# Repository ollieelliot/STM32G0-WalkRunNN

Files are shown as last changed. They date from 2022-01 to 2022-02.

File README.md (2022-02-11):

# Motion detection on an STM32G0 microcontroller

# Hardware: 
  - The Schematic and PCB is designed in KiCad and uses the STM32G041J6M6 ARM Cortex-M0 Microcontroller together with an MPU6050 (Gyroscope and Accelerometer).

# Software (currently working on):
- Uses a neural network trained in Python and [emlearn](https://github.com/emlearn/emlearn) to save the weights, biases and activation functions to a header file in order to run inference in C.

# Pictures:
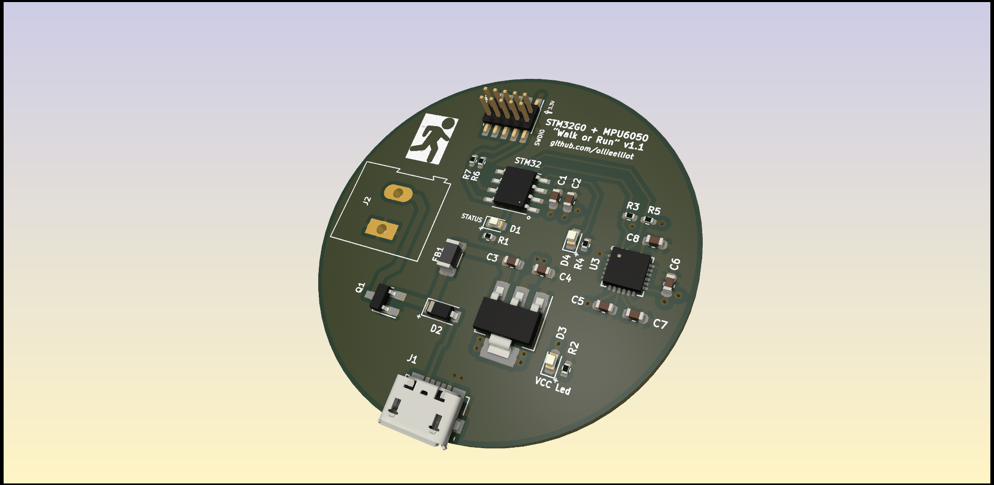
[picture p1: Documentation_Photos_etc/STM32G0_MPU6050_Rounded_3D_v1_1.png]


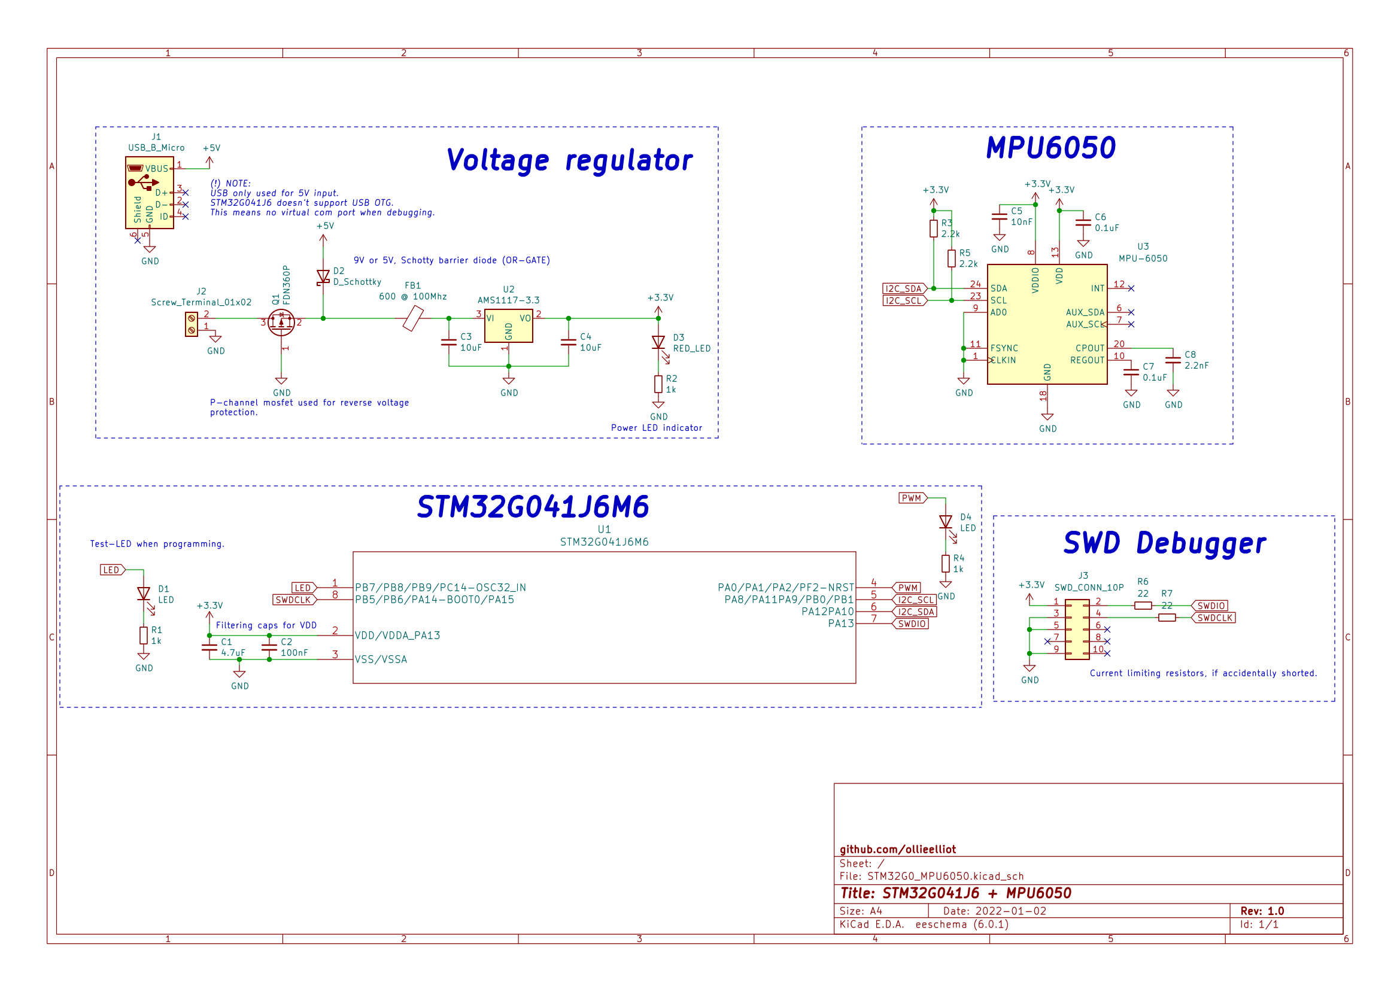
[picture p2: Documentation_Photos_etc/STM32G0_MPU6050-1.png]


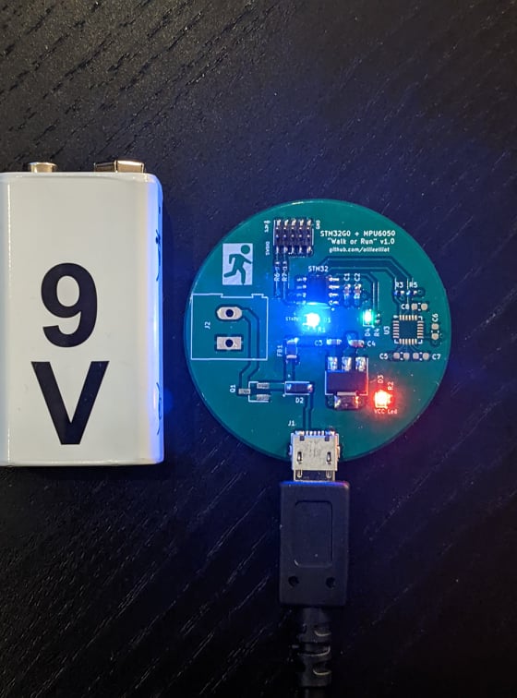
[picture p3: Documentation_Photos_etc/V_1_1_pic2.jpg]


Currently everything except the MPU6050 is soldered due to delayed shipment.

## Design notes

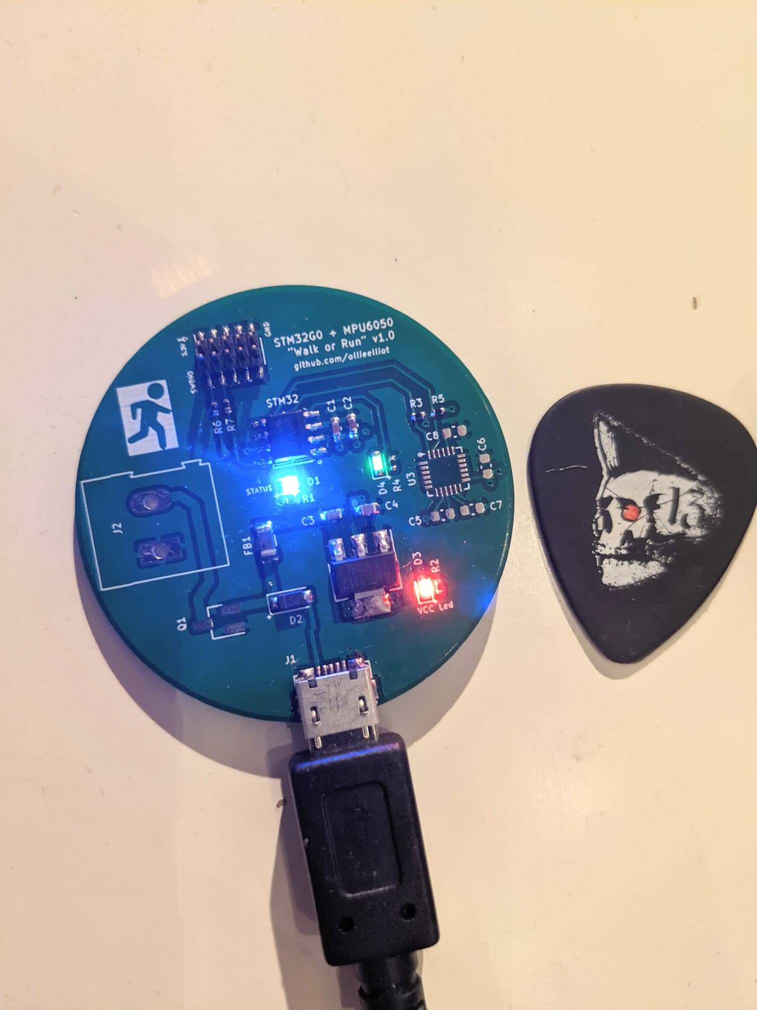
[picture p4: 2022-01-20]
Documentation_Photos_etc/V_1_1_pic3.jpg

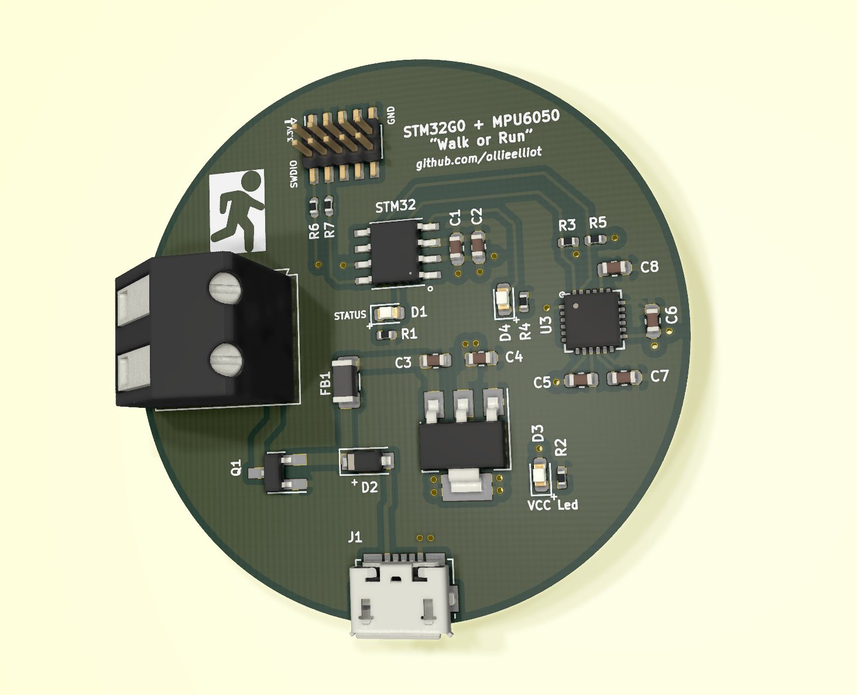
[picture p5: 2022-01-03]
Documentation_Photos_etc/STM32G0_MPU6050_Rounded_3D.png

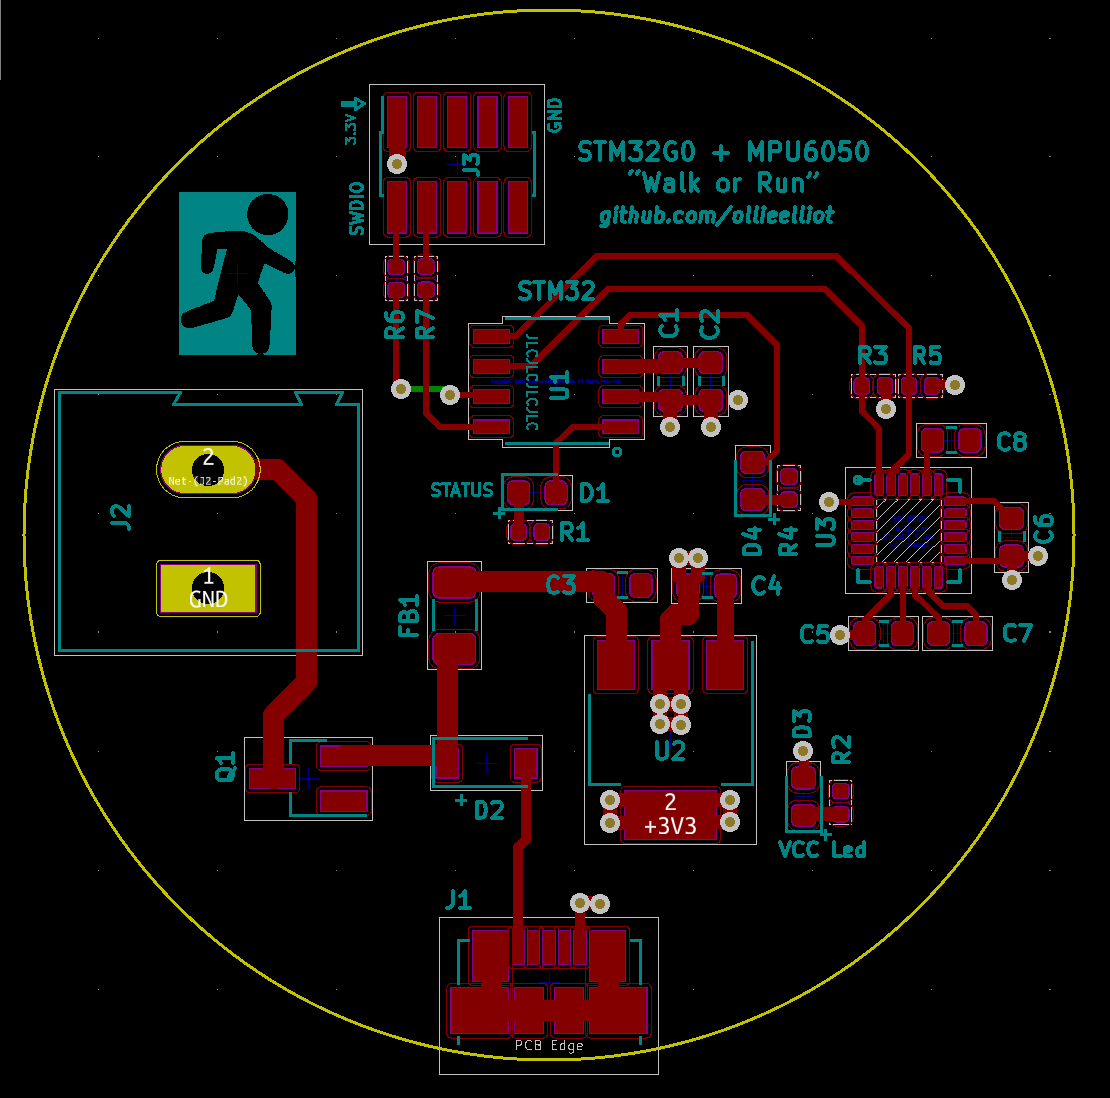
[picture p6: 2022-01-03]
Documentation_Photos_etc/STM32G0_MPU6050_Rounded.png

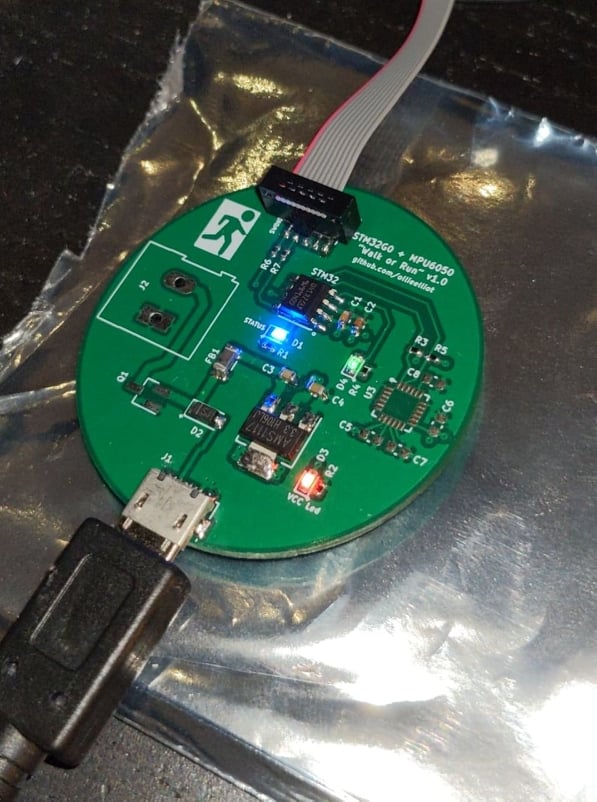
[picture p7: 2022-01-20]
Documentation_Photos_etc/V_1_1_pic1.jpg

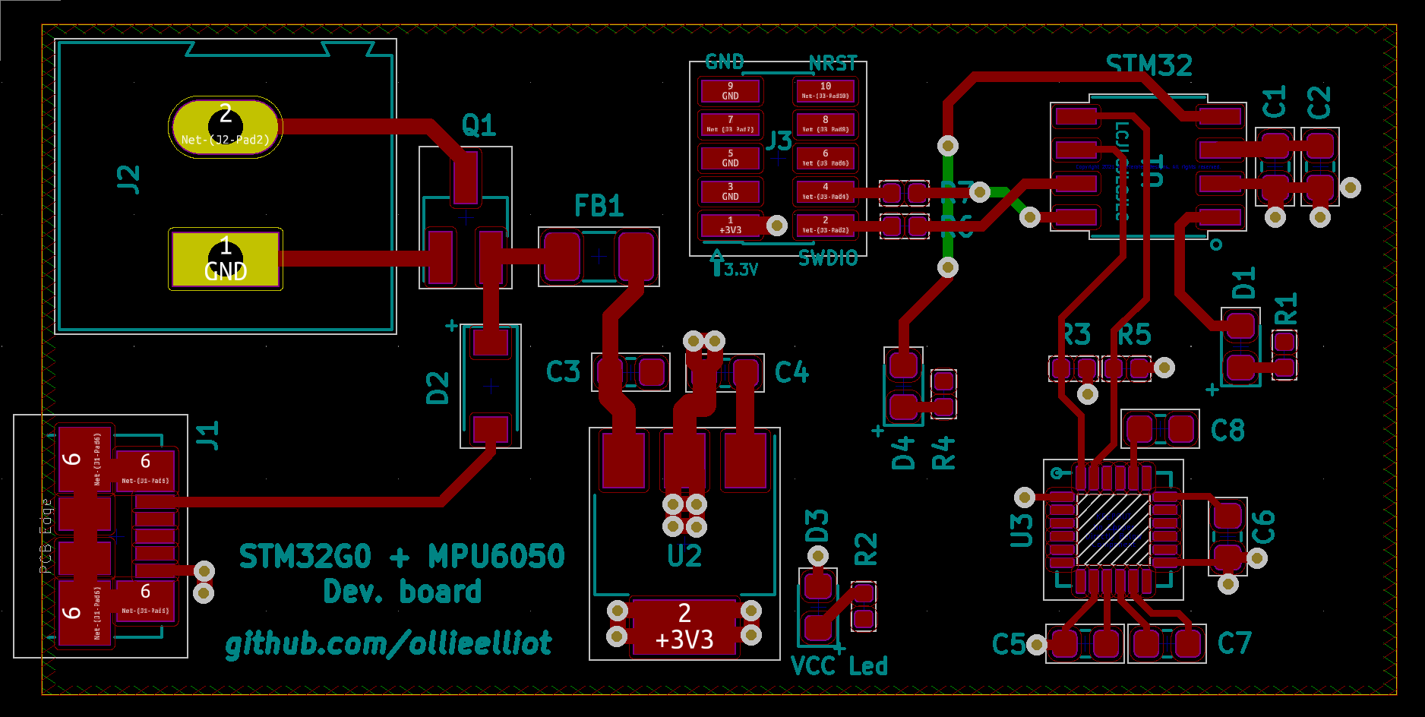
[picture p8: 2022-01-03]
Documentation_Photos_etc/STM32G0_MPU6050_Rectangle.png

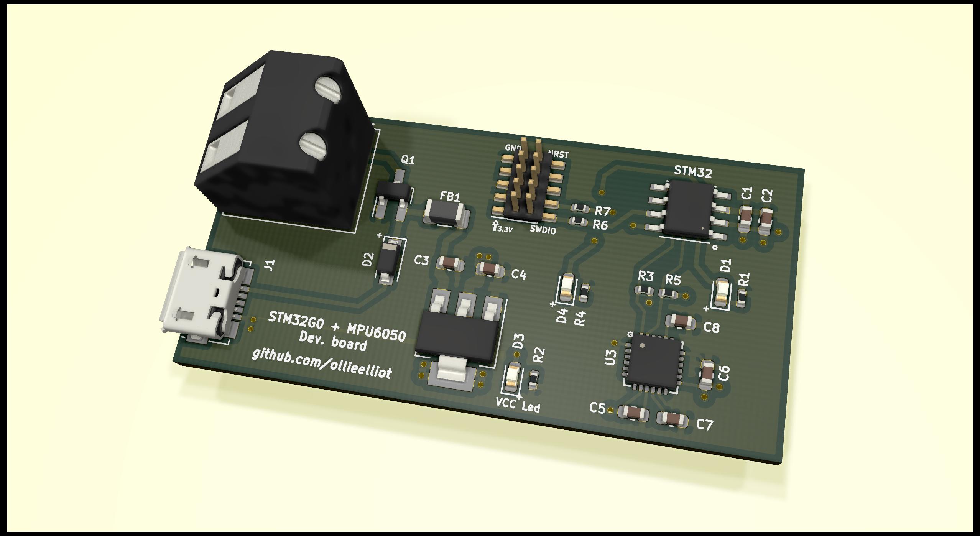
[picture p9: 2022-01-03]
Documentation_Photos_etc/STM32G0_MPU6050_Rectangle_3D.jpg

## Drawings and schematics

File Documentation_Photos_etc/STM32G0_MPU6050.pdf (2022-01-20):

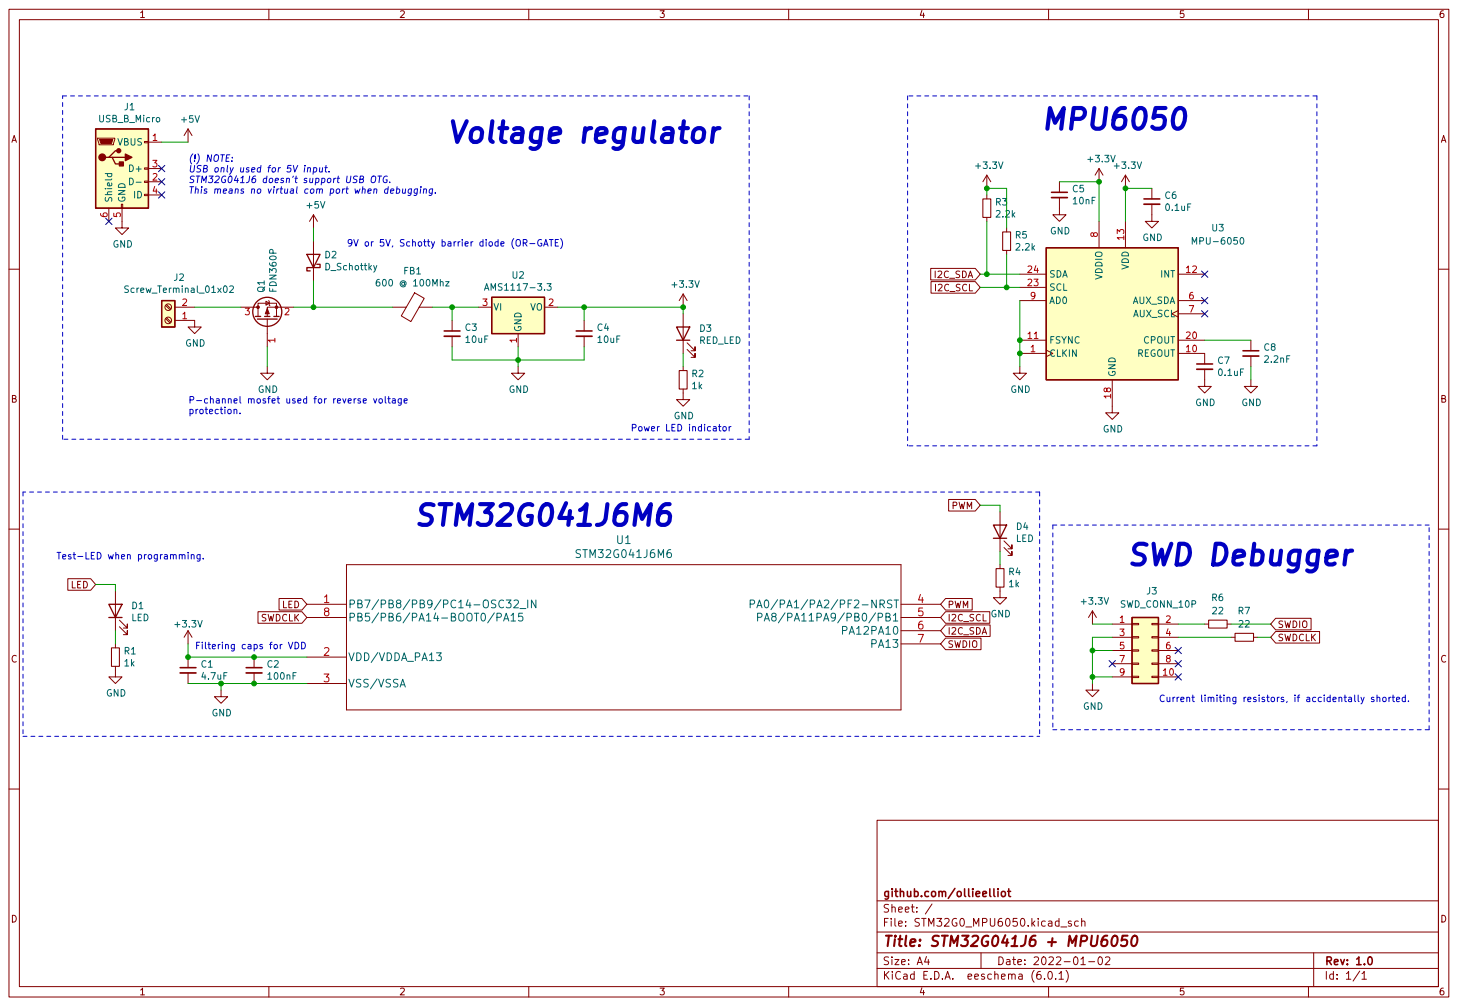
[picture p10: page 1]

(!) NOTE:
USB only used for 5V input.
This means no virtual com port when debugging.

9V or 5V, Schotty barrier diode (OR-GATE)

Power LED indicator P-channel mosfet used for reverse voltage
protection.

SWD Debugger Test-LED when programming.

Current limiting resistors, if accidentally shorted.

File: STM32G0_MPU6050.kicad_sch Sheet: / github.com/ollieelliot

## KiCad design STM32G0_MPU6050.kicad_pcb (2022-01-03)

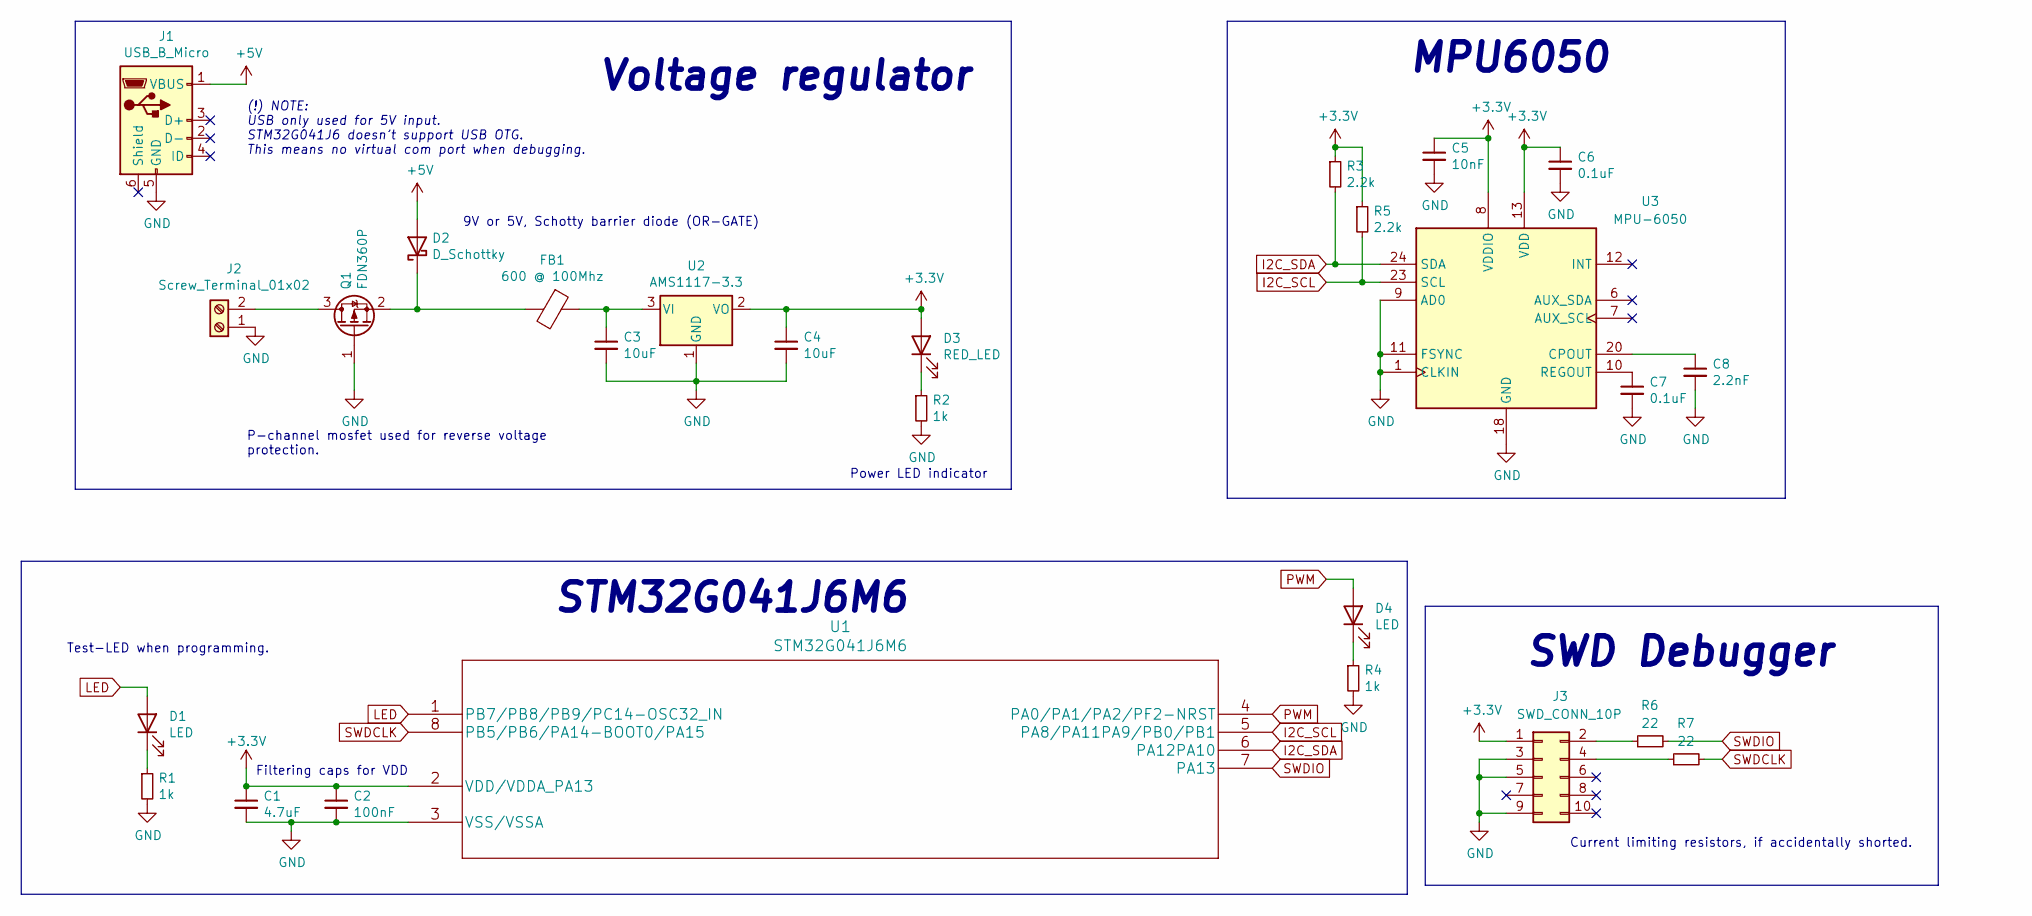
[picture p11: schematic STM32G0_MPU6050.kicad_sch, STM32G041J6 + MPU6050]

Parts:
C1: 4.7uF; C_0603_1608Metric
C2: 100nF; C_0603_1608Metric
C3, C4: 10uF; C_0603_1608Metric
C5: 10nF; C_0603_1608Metric
C6, C7: 0.1uF; C_0603_1608Metric
C8: 2.2nF; C_0603_1608Metric
D1, D4: LED; LED_0603_1608Metric
D2: D_Schottky; D_SOD-123
D3: RED_LED; LED_0603_1608Metric
FB1: 600 @ 100Mhz; L_1206_3216Metric
J1: USB_B_Micro; USB_Micro-B_Molex_47346-0001
J2: Screw_Terminal_01x02; TerminalBlock_Altech_AK300-2_P5.00mm
J3: SWD_CONN_10P; PinHeader_2x05_P1.27mm_Vertical_SMD
Q1: FDN360P; SOT-23_Handsoldering
R1, R2, R4: 1k; R_0402_1005Metric
R3, R5: 2.2k; R_0402_1005Metric
R6, R7: 22; R_0402_1005Metric
U1: STM32G041J6M6
U2: AMS1117-3.3; SOT-223-3_TabPin2
U3: MPU-6050; InvenSense_QFN-24_4x4mm_P0.5mm

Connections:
+3V3: C1.1, C2.1, C4.1, C5.1, C6.1, D3.2 (A), J3.1, R3.1, R5.1, U1.2 (VDD/VDDA_PA13), U2.2 (VO), U3.8 (VDDIO), U3.13 (VDD)
+5V: D2.2 (A), J1.1 (VBUS)
GND: C1.2, C2.2, C3.2, C4.2, C5.2, C6.2, C7.2, C8.2, J1.5 (GND), J2.1, J3.3, J3.5, J3.9, Q1.1 (G), R1.2, R2.2, R4.2, U1.3 (VSS/VSSA), U2.1 (GND), U3.1 (CLKIN), U3.9 (AD0), U3.11 (FSYNC), U3.18 (GND)
I2C_SCL: R5.2, U1.5 (PA8/PA11PA9/PB0/PB1), U3.23 (SCL)
I2C_SDA: R3.2, U1.6 (PA12PA10), U3.24 (SDA)
LED: D1.2 (A), U1.1 (PB7/PB8/PB9/PC14-OSC32_IN)
unnamed: C3.1, FB1.1, U2.3 (VI)
unnamed: C7.1, U3.10 (REGOUT)
unnamed: C8.1, U3.20 (CPOUT)
unnamed: D1.1 (K), R1.1
unnamed: D2.1 (K), FB1.2, Q1.2 (S)
unnamed: D3.1 (K), R2.1
unnamed: D4.1 (K), R4.1
unnamed: J2.2, Q1.3 (D)
unnamed: J3.2, R6.1
unnamed: J3.4, R7.1
PWM: D4.2 (A), U1.4 (PA0/PA1/PA2/PF2-NRST)
SWDCLK: R7.2, U1.8 (PB5/PB6/PA14-BOOT0/PA15)
SWDIO: R6.2, U1.7 (PA13)

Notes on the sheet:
Voltage regulator
SWD Debugger
(!) NOTE: USB only used for 5V input. STM32G041J6 doesn’t support USB OTG. This means no virtual com port when debugging.
STM32G041J6M6
Power LED indicator
P-channel mosfet used for reverse voltage protection.
Filtering caps for VDD
MPU6050
Test-LED when programming.
9V or 5V, Schotty barrier diode (OR-GATE)
Current limiting resistors, if accidentally shorted.

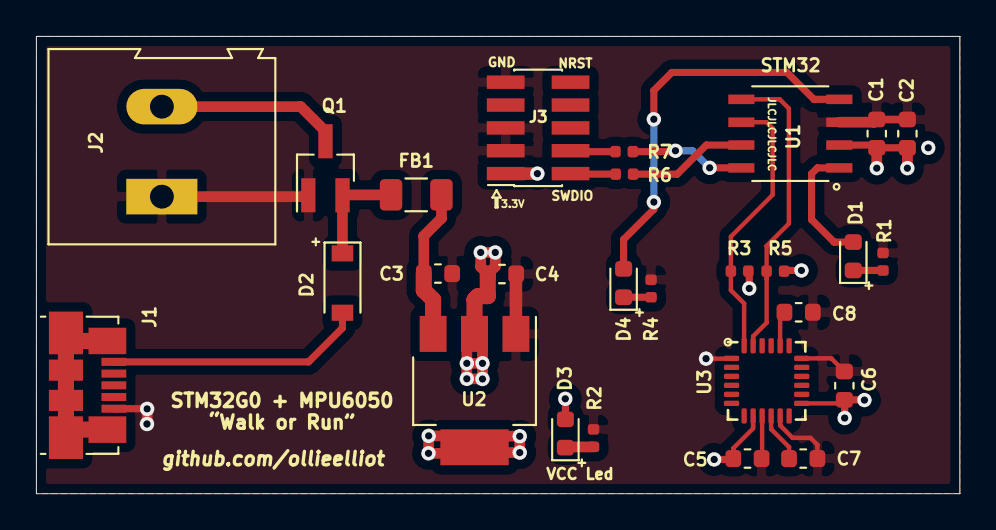
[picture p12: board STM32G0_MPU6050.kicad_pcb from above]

Board: 2 copper layers, 51.3 x 25.4 mm, 27 parts (0 on the bottom side), 19 nets.

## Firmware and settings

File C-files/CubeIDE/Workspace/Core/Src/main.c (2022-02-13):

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
/* Includes ------------------------------------------------------------------*/
#include "main.h"

/* USER CODE BEGIN Includes */
#include "TJ_MPU6050.h"


/* USER CODE END Includes */

I2C_HandleTypeDef hi2c2;

TIM_HandleTypeDef htim2;

void SystemClock_Config(void);
static void MX_GPIO_Init(void);
static void MX_I2C2_Init(void);
static void MX_TIM2_Init(void);
/* USER CODE BEGIN 0 */
RawData_Def AccelRaw, GyroRaw;
ScaledData_Def AccelScaled, GyroScaled, AccelCali;

//float SCALING_FACTOR_2g = 2000.0f/32768.0f;
//float SCALING_FACTOR_4g = 4000.0f/32768.0f;
float SCALING_FACTOR_8g = 8000.0f/32768.0f;
//float SCALING_FACTOR_16g = 2000.0f/32768.0f;

/* USER CODE END 0 */

/**
  * @brief  The application entry point.
  * @retval int
  */
int main(void)
{
  /* USER CODE BEGIN 1 */

	MPU_ConfigTypeDef MpuConfig;

	//float gyro_x;
	//float gyro_y;
	//float gyro_z;

	float accel_x;
	float accel_y;
	float accel_z;



	//int predictions = 0;


  /* USER CODE END 1 */

  /* MCU Configuration--------------------------------------------------------*/

  /* Reset of all peripherals, Initializes the Flash interface and the Systick. */
  HAL_Init();

  /* USER CODE BEGIN Init */


  MPU6050_Init(&hi2c2);
  //2. Configure Accel and Gyro parameters
  MpuConfig.Accel_Full_Scale = AFS_SEL_2g;
  MpuConfig.ClockSource = Internal_8MHz;
  MpuConfig.CONFIG_DLPF = DLPF_5_Hz;
  MpuConfig.Gyro_Full_Scale = FS_SEL_250;
  MpuConfig.Sleep_Mode_Bit = 0;  //1: sleep mode, 0: normal mode
  MPU6050_Config(&MpuConfig);

  //_Accel_Cali(63, 85, 14, 28, 833, 850); //Calibrate the accelerometer



  /* USER CODE END Init */

  /* Configure the system clock */
  SystemClock_Config();

  /* Initialize all configured peripherals */
  MX_GPIO_Init();
  MX_I2C2_Init();
  MX_TIM2_Init();
  /* USER CODE BEGIN 2 */


  HAL_GPIO_WritePin(STATUS_GPIO_Port, STATUS_Pin, GPIO_PIN_RESET);
  //HAL_GPIO_WritePin(STATUS2_GPIO_Port, STATUS2_Pin, GPIO_PIN_RESET);

  HAL_TIM_PWM_Start(&htim2, TIM_CHANNEL_3);
  int32_t CH3_DC = 0;

  /* USER CODE END 2 */

  /* Infinite loop */
  /* USER CODE BEGIN WHILE */
  while (1)
  {
		  while(CH3_DC < 65535)
		  {
			  HAL_GPIO_WritePin(STATUS_GPIO_Port, STATUS_Pin, GPIO_PIN_SET);
			  TIM2->CCR3 = CH3_DC;
			  CH3_DC += 250;
			  HAL_Delay(1);
		  }
		  while(CH3_DC > 0)
		  {
			  HAL_GPIO_WritePin(STATUS_GPIO_Port, STATUS_Pin, GPIO_PIN_RESET);
			  TIM2->CCR3 = CH3_DC;
			  CH3_DC -= 250;
			  HAL_Delay(1);
		  }

	  /*
	  //Scaled data

	  MPU6050_Get_Accel_Cali(&AccelCali);
	  //MPU6050_Get_Accel_Scale(&AccelScaled);
	  //MPU6050_Get_Gyro_Scale(&GyroScaled);

	  //gyro_x = GyroScaled.x;
      //gyro_y = GyroScaled.y;
	  //gyro_z = GyroScaled.z;

	  accel_x = AccelCali.x * SCALING_FACTOR_8g;
	  accel_y = AccelCali.y;
	  accel_z = AccelCali.z;



	  float input_data[3] = {accel_x, accel_y, accel_z};	//Scale down and subtract offset, accel_y/15 - 115, accel_z/15 - 75
	  //< accel_y <= 500

	  //pitch_angle = atanf(accel_y/accel_z);

	  if(accel_y == 500)
		  HAL_GPIO_WritePin(STATUS_GPIO_Port, STATUS_Pin, GPIO_PIN_SET);
	  else
		  HAL_GPIO_WritePin(STATUS_GPIO_Port, STATUS_Pin, GPIO_PIN_RESET);


	  if(accel_y < 200)
	  		  HAL_GPIO_WritePin(STATUS2_GPIO_Port, STATUS2_Pin, GPIO_PIN_SET);
	  	  else
	  		  HAL_GPIO_WritePin(STATUS2_GPIO_Port, STATUS2_Pin, GPIO_PIN_RESET);
	  */



	  //int32_t prediction = eml_net_predict(&runwalkNN_acc, input_data, 3);

	  /* Activate LED if enough running predictions where done within some time frame */
	  /*
	  if(prediction == 1)
	  {
		  predictions = predictions + 3;
		  if(predictions > 100)
			  predictions = 100;
	  }

	  else
	  {
		  predictions--;
		  if(predictions < 0)
			  predictions = 0;
	  }


	  if (predictions >= 50)
		  HAL_GPIO_WritePin(LD2_GPIO_Port, LD2_Pin, GPIO_PIN_SET);
	  else
		  HAL_GPIO_WritePin(LD2_GPIO_Port, LD2_Pin, GPIO_PIN_RESET);


	  bufflen = sprintf(buff, "a_x: %f, a_y: %f, a_z: %f, Prediction: %ld \r", input_data[0], input_data[1], input_data[2], prediction);
	  HAL_UART_Transmit(&huart2, (uint8_t *)buff, bufflen, 100);
	  */













	  //HAL_Delay(100);







    /* USER CODE END WHILE */

    /* USER CODE BEGIN 3 */
  }
  /* USER CODE END 3 */
}

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


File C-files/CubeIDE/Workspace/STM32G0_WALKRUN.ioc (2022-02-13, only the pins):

Mcu.UserName=STM32G041J6Mx
PA13.Signal=SYS_SWDIO
PA14-BOOT0.Signal=SYS_SWCLK
PA2.GPIO_Label=PWM_LED
PA2.Signal=S_TIM2_CH3
PB7.GPIO_Label=STATUS
PB7.Signal=GPIO_Output

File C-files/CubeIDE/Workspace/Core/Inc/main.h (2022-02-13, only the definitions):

#define STATUS_Pin GPIO_PIN_7
#define STATUS_GPIO_Port GPIOB
#define PWM_LED_Pin GPIO_PIN_2
#define PWM_LED_GPIO_Port GPIOA

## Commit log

2022-01-03 Init commit
    [STM32G0_MPU6050.kicad_pcb, STM32G0_MPU6050.sch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]
2022-01-03 Added more photos
    Added photos of the rounded PCB version
2022-01-04 Added runwalk neural network with trained on accelerometer only
2022-01-20 Setup STM32Cube
    [STM32G0_MPU6050.kicad_sch, STM32G0_MPU6050_circle.kicad_pcb]
2022-01-20 Changed SWD pin footprint
    -Changed 2x5 pin to header instead of socket. Caused orientation problems with pins on the Jtag 10-pin adapter for ST-Link debugger.
    [STM32G0_MPU6050_circle.kicad_pcb]
2022-01-20 Added schematic pdf
    [STM32G0_MPU6050.kicad_sch]

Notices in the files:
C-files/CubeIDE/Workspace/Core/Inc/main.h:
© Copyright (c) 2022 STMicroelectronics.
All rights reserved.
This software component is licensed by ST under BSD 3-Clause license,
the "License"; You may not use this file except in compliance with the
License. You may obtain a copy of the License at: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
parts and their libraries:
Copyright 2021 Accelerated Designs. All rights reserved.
